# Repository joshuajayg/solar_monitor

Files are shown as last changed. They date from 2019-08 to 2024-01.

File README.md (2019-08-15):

# Solar Monitor

This is a solar power production and use monitoring system based on the LTC4151 IC by Analog.  Data is read by an ESP8266, sent over wifi using MQTT to a Raspberry Pi, stored in a database, then uploaded to a hosted webserver for display.  It is a work in progress but I plan to share all my scripts, web pages, and hardware designs here to help me solve problems and guide people in the right direction who want to setup a similar system.

You can see the system in work at http://yeolecabin.com/solar_complete.php



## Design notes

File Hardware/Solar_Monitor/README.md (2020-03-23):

The board uses six LTC4151-2 ICs, an ESP8266 running NODEMCU and one DROK buck converter.

The wires run from the board to the current shunts needs to be twisted pair wires.  This cuts down on EMI by common mode rejection.  For short runs, CAT5 wire works fine.

When adding a external input to D3, there is a voltage divider used to drop the voltage to 3.3V at the MCU.  You need to calculate these values as follows:
Vout = (Vin * R3) / (R4 + R3)

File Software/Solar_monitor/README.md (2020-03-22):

#Requirements:

    LTC4151 library from https://github.com/kerrydwong/LTC4151
    ESP8266 board zip

Arduino IDE version used: 1.8.5

ESP8266 board version: 2.4.2

Remember to update the "ssid", "password", "mqtt_server", "batteryCapacity", and "batteryEfficiency" to match your setup.

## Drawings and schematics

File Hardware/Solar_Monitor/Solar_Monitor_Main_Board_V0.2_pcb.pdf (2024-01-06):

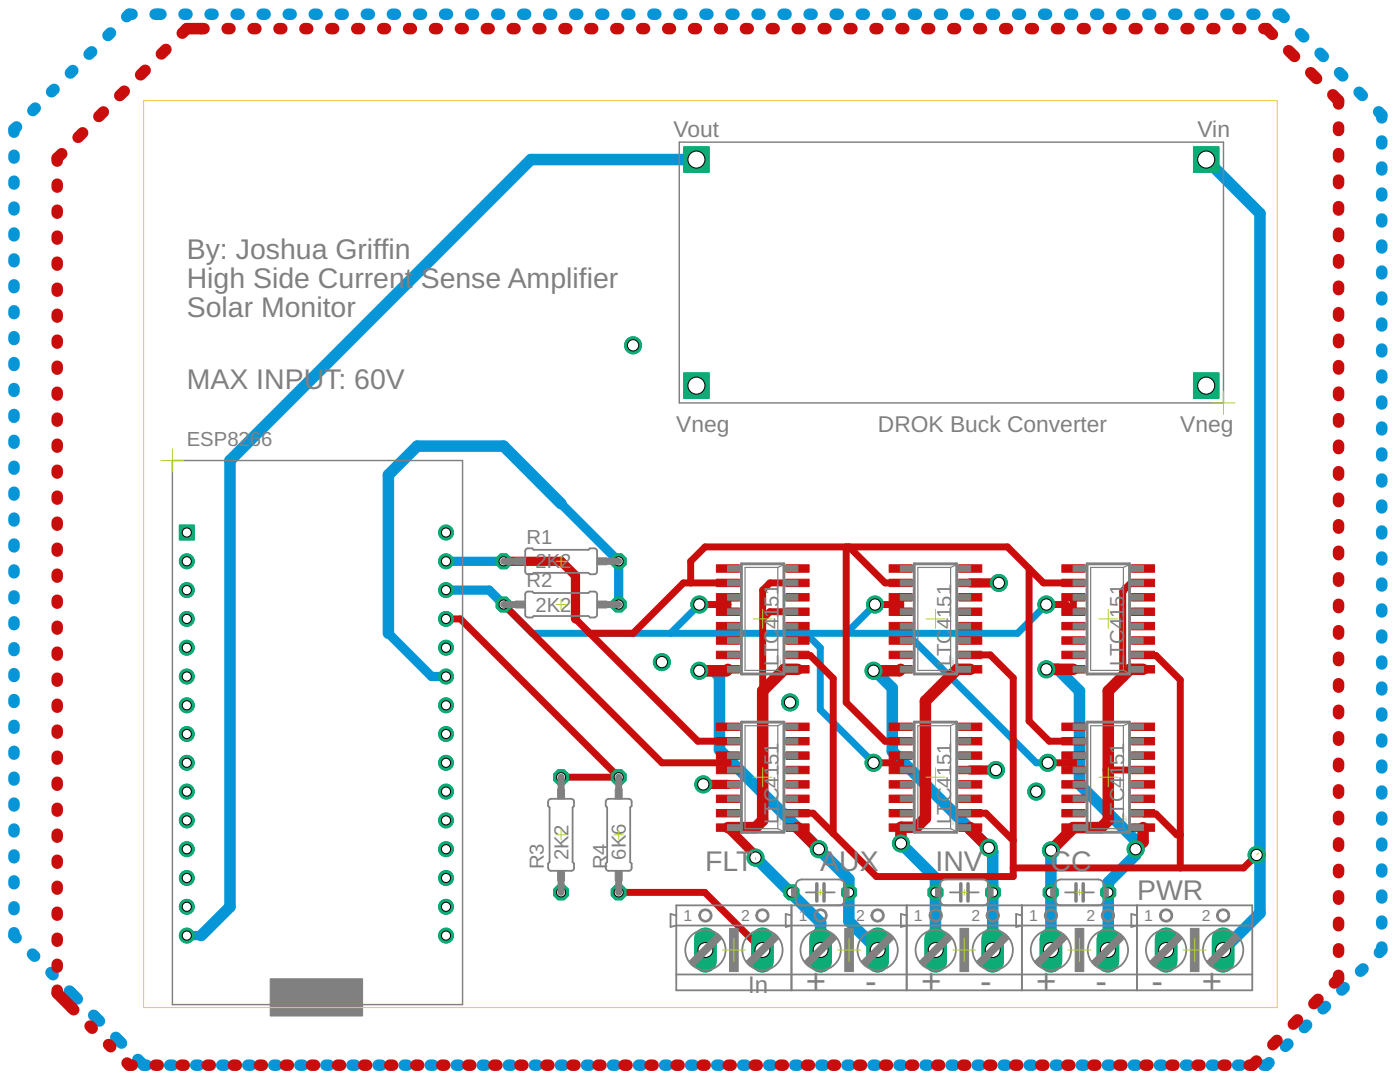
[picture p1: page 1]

By: Joshua Griffin
High Side Current Sense Amplifier
Solar Monitor

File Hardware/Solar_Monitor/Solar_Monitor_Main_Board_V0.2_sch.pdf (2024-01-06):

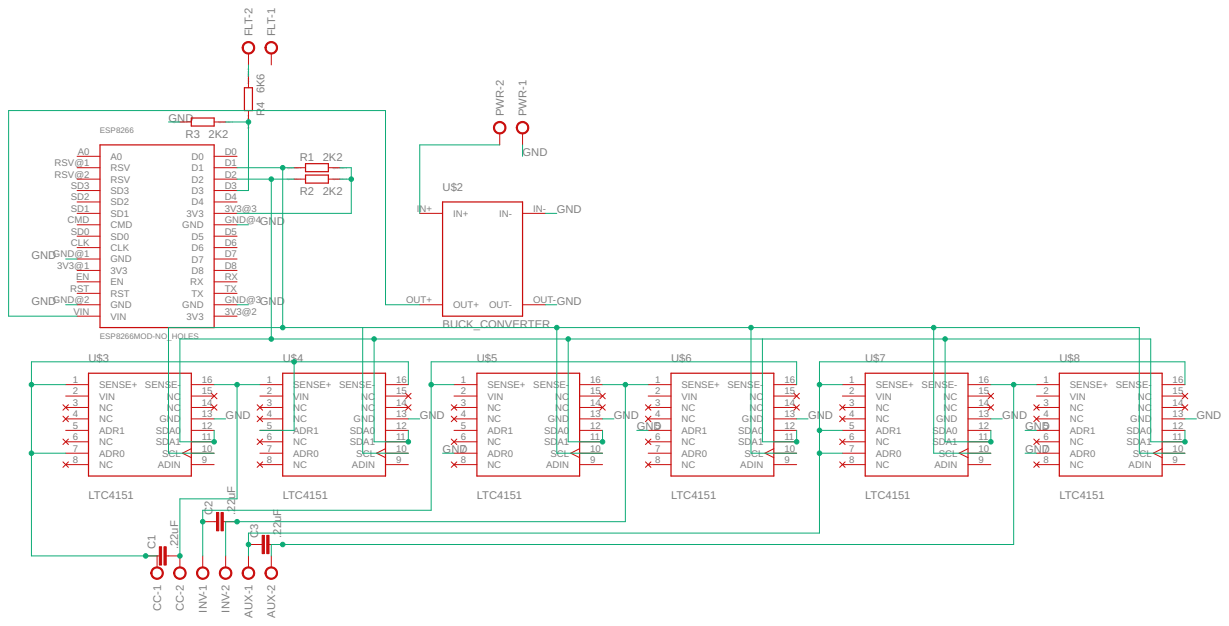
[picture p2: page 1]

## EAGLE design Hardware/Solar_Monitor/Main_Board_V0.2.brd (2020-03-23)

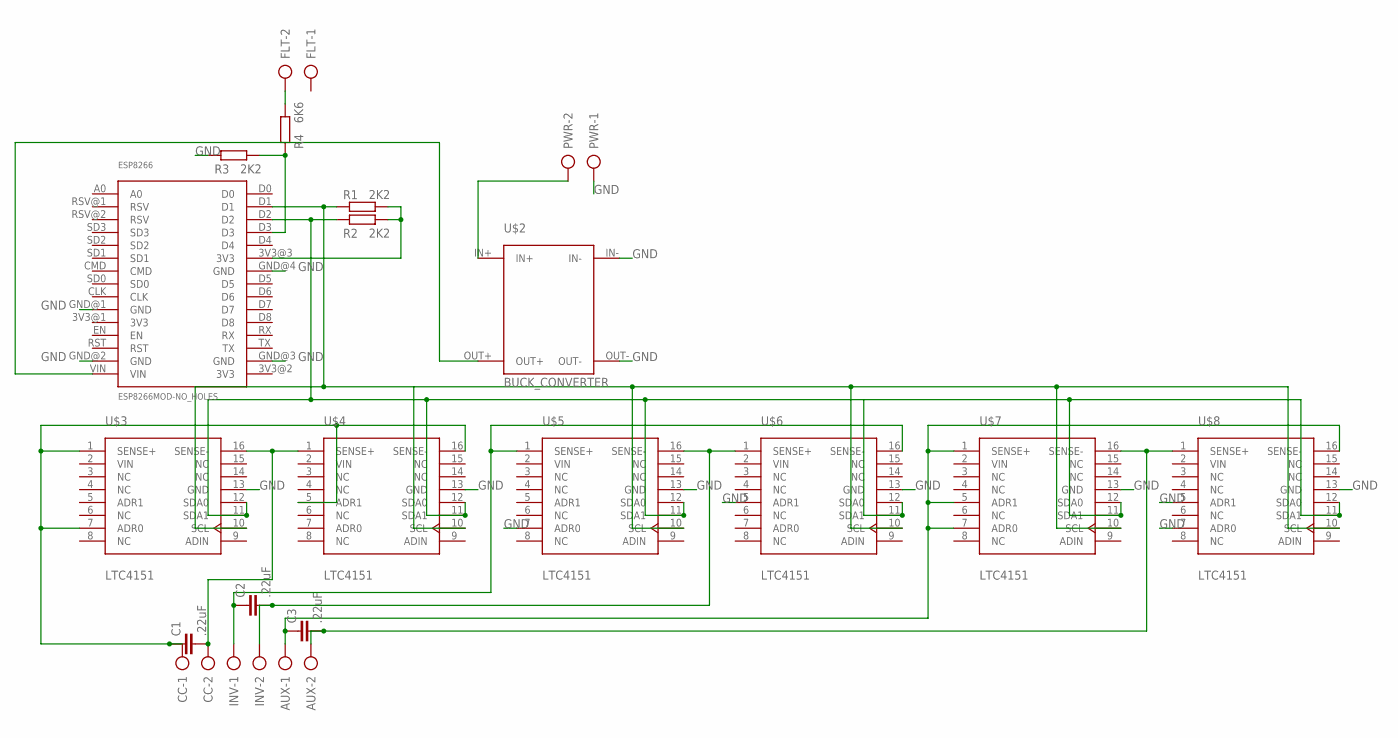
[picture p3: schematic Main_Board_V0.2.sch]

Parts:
AUX: AK500/2
C1, C2, C3: .22uF; C050-024X044
CC: AK500/2
ESP8266: ESP8266MOD-NO_HOLES
FLT: AK500/2
INV: AK500/2
PWR: AK500/2
R1, R2, R3: 2K2; 0207/10
R4: 6K6; 0207/10
U$2: BUCK_CONVERTER
U$3, U$4, U$5, U$6, U$7, U$8: LTC4151; SO16

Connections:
GND: ESP8266.GND@1 (GND), ESP8266.GND@2 (GND), ESP8266.GND@3 (GND), ESP8266.GND@4 (GND), PWR.1, R3.1, U$2.IN-, U$2.OUT-, U$3.13 (GND), U$4.13 (GND), U$5.7 (ADR0), U$5.13 (GND), U$6.5 (ADR1), U$6.13 (GND), U$7.13 (GND), U$8.5 (ADR1), U$8.7 (ADR0), U$8.13 (GND)
unnamed: FLT.2, R4.2
unnamed: ESP8266.D3, R3.2, R4.1
unnamed: ESP8266.VIN, U$2.OUT+
unnamed: C1.1, CC.1, U$3.1 (SENSE+), U$3.7 (ADR0), U$4.5 (ADR1), U$4.16 (SENSE-)
unnamed: C1.2, CC.2, U$3.16 (SENSE-), U$4.1 (SENSE+)
unnamed: C2.1, INV.1, U$5.1 (SENSE+), U$6.16 (SENSE-)
unnamed: C2.2, INV.2, U$5.16 (SENSE-), U$6.1 (SENSE+)
unnamed: AUX.1, C3.1, U$7.1 (SENSE+), U$7.5 (ADR1), U$7.7 (ADR0), U$8.16 (SENSE-)
unnamed: AUX.2, C3.2, U$7.16 (SENSE-), U$8.1 (SENSE+)
unnamed: ESP8266.D2, R2.1, U$3.11 (SDA1), U$3.12 (SDA0), U$4.11 (SDA1), U$4.12 (SDA0), U$5.11 (SDA1), U$5.12 (SDA0), U$6.11 (SDA1), U$6.12 (SDA0), U$7.11 (SDA1), U$7.12 (SDA0), U$8.11 (SDA1), U$8.12 (SDA0)
unnamed: ESP8266.3V3@3 (3V3), R1.2, R2.2
unnamed: ESP8266.D1, R1.1, U$3.10 (SCL), U$4.10 (SCL), U$5.10 (SCL), U$6.10 (SCL), U$7.10 (SCL), U$8.10 (SCL)
VIN: PWR.2, U$2.IN+, U$3.2 (VIN), U$4.2 (VIN), U$5.2 (VIN), U$6.2 (VIN), U$7.2 (VIN), U$8.2 (VIN)

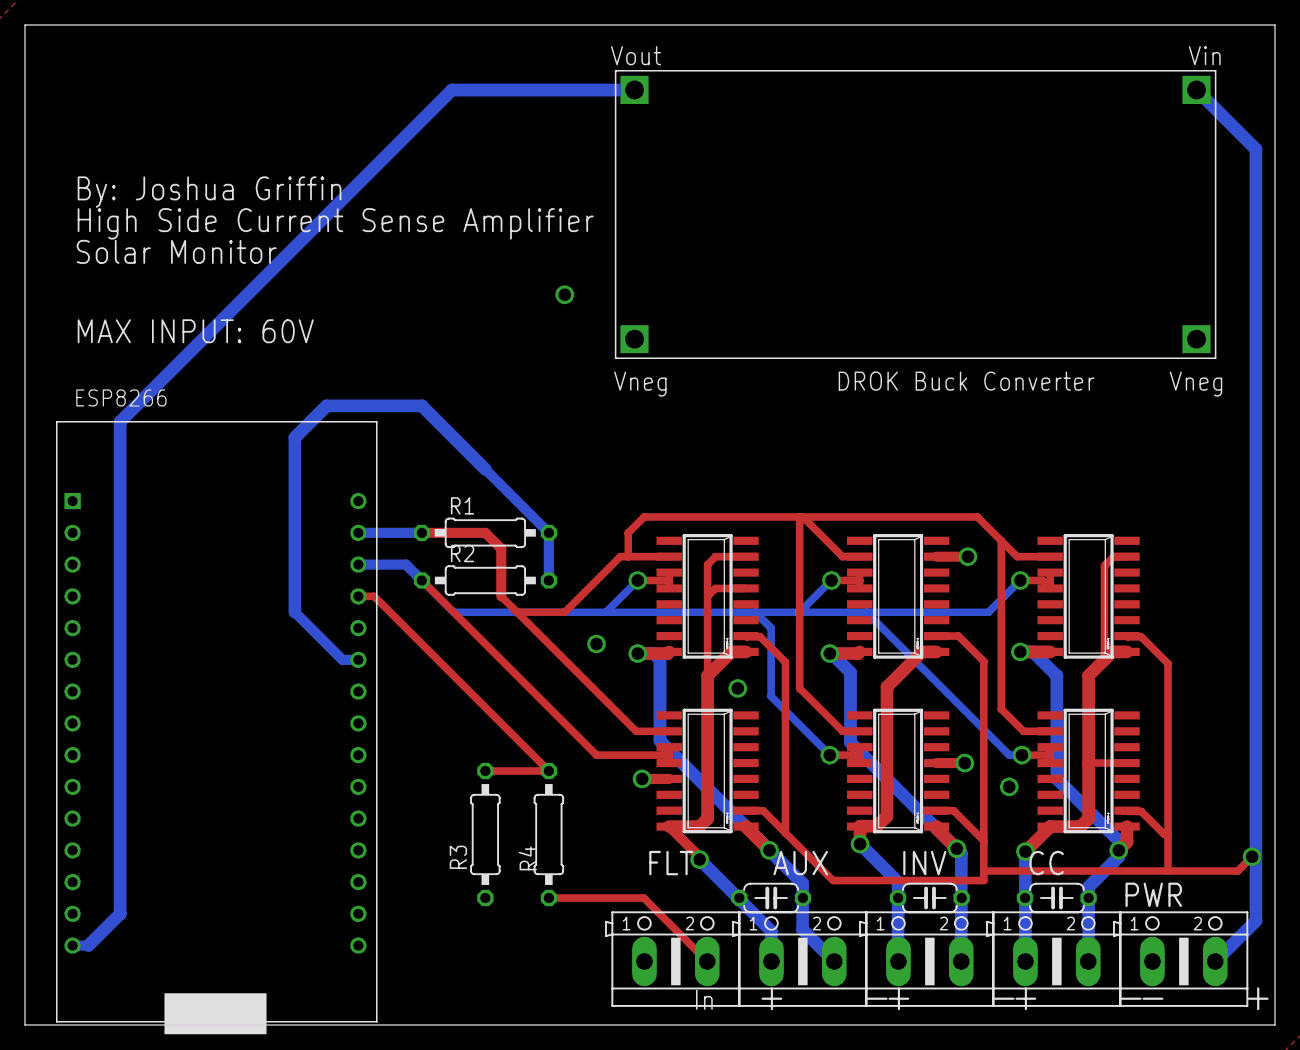
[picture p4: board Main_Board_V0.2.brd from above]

Board: 2 copper layers, 100.0 x 80.0 mm, 20 parts (0 on the bottom side), 14 nets.

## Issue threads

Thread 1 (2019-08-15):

Load on inverter causes false indications on auxiliary

joshuajayg, 2019-08-15:
When the auxiliary bus has no load and the inverter is loaded (which it always it), the auxiliary sensors indicate a positive amperage.  This issue is significant in that it causes bad state of charge calculations over the course of several hours.  If the inverter idles at -3.5A all night and the auxiliary bus is indicating 1.2A, the SOC will be miscalculated by 30% over that time.

I know very little about PCB layout so would appreciate help.
Any ideas @csatt @mohitbhoite ?

The noise on the Auxiliary graph is visible when comparing amp readings across the different sensors at the same time.
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

joshuajayg, 2019-08-24:
Looks like I'm picking up a lot of noise on the sense lines.  Possibly the inverter carrier frequency used to create the sine wave.  Higher frequency is close to 10khz.  I'll change to shielded wires and I'll move the board further away from the inverter and see how that works.  The 60hz dip makes sense.  Every time the inverter produces a sine wave, there is a pulse of power input specifically at 90 degrees.  Also, the carrier frequency increases amplitude when the 60hz voltage dips which would coincide with increased load.  It's the high voltage carrier frequency that bothers me.
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

joshuajayg, 2019-09-07:
I have replaced the cables with twisted pair and the error is greatly improved.  I have also redesigned the PCB to account for an an imbalance in loading the sense wires.  Both ICs on one channel were designed to pull their Vin current from one sense line.  This would cause a small (170uV) drop in voltage across the sense wire if it's 3 feet long and 24awg (typical for CAT5).  Now the IC Vin lines are tied to the same input as the buck converter input.  I will be milling a new PCB soon to test this.

joshuajayg, 2020-03-22:
I have redesigned the board to allow a separate power supply line to feed all the current sense amplifier ICs.  This has fixed all but the smallest about of ripple in the "auxiliary" readings.  The past couple months of testing have shown a negligible amount of error in the auxiliary and therefore calculated battery readings.

Closed 2020-03-22.

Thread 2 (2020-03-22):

Request for input from charge controller aux output

joshuajayg, 2020-03-22:
The Outback MX charge controller series allows the user to setup and output based upon current charge points.  It would be handy to have a circuit designed to take this output from the charge controller and send its status through MQTT to the server.

joshuajayg, 2020-03-23:
Added a voltage divider, input terminal, and routing to D3 for external measurement.  Also added ability to read this value in the sketch though it has not been tested.  Resistor value must be chosen to not allow more than 3.3V to the MCU.

Closed 2020-03-23.

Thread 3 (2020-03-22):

Incorrect label for max voltage

joshuajayg, 2020-03-22:
The max voltage label on the PCB is 90V.  This is based on the current sense amplifier datasheet.  However, the DROK buck converter has a lower max voltage of 60V.

joshuajayg, 2020-03-23:
V0.2 of the board now says max input is 60V to match the buck converter limit.

Closed 2020-03-23.

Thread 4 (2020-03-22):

adin pin not used but measurement called in sketch

joshuajayg, 2020-03-22:
The LTC4151 has a pin available to measure an external voltage (different than battery voltage) but the pin is not broken out on the board.  Calling a reading on this pin is a waste of memory.

joshuajayg, 2020-03-23:
Removed all calls to measure ADIN from sketch.

Closed 2020-03-23.

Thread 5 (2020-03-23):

It would be nice to be able to set the initial values for several reported values

joshuajayg, 2020-03-23:
Things like state of charge, amphours, and watthours get reset when you remove and add power or re-upload the sketch.  It would be handy to be able to set these initial values when uploading the sketch.

joshuajayg, 2020-03-23:
Added initial values in the sketch and a check up setup() to set these initial values in the global variables.

Closed 2020-03-23.

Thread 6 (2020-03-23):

Request for SPIFFS storage of last values

joshuajayg, 2020-03-23:
When the board looses power, the "initial values" are re-read and applied to the current global variables.  A better solution would be to periodically store globals in SPIFFS so that a power cycle of the board, the latest values get re-saved as the initial global variables.

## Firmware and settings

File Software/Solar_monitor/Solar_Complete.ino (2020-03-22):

#include <Wire.h>
#include <LTC4151.h>
#include <ESP8266WiFi.h>
#include <ESP8266mDNS.h>
#include <WiFiUdp.h>
#include <ArduinoOTA.h>
#include <PubSubClient.h>

const char* ssid = "Your_Access_Point";
const char* password = "Your_Password";
const char* mqtt_server = "Server_IP";

const float batteryEfficiency = .97;  // How much of the charge the batteries absorb
const float batteryCapacity = 450;  // Amp Hours

float initialBatteryAmpHours = 450;
float initialInverterWattHours = -2265;
float initialInverterAmpHours = -88.15;
float initialChargeControllerAmpHours = 163.54;
float initialChargeControllerWattHours = 4666;

// Input pins
//#define floatPin D3
  
// Tracking time
unsigned long lastTime1;
unsigned long lastTime2;
unsigned long lastTime3;
unsigned long lastTime4;
unsigned long length1;
unsigned long length2;
unsigned long length3;
unsigned long length4;

// MQTT setup
WiFiClient espClient;
PubSubClient client(espClient);
unsigned long lastMsg = 0;
char msg1[8];
char msg2[8];
char msg3[8];
char msg4[8];
char msg5[8];
char msg6[8];
char msg7[8];
char msg8[8];
char msg9[8];
char msg10[8];
char msg11[8];
char msg12[8];
char msg13[8];
char msg14[8];
char msg15[8];
char msg16[8];
char msg17[8];
char msg18[6];

// Define sensors
LTC4151 sensor1;
LTC4151 sensor2;
LTC4151 sensor3;
LTC4151 sensor4;
LTC4151 sensor5;
LTC4151 sensor6;

//Array setup
const int numReadings1 = 20;
float readings1[numReadings1];
int readIndex1 = 0;
float total1 = 0;
float amp1 = 0;

const int numReadings2 = 20;
float readings2[numReadings2];
int readIndex2 = 0;
float total2 = 0;
float amp2 = 0;

const int numReadings3 = 20;
float readings3[numReadings3];
int readIndex3 = 0;
float total3 = 0;
float amp3 = 0;

const int numReadings4 = 20;
float readings4[numReadings4];
int readIndex4 = 0;
float total4 = 0;
float amp4 = 0;

const int numReadings5 = 20;
float readings5[numReadings5];
int readIndex5 = 0;
float total5 = 0;
float amp5 = 0;

const int numReadings6 = 20;
float readings6[numReadings6];
int readIndex6 = 0;
float total6 = 0;
float amp6 = 0;

// Values
float inverterAmps;
float inverterVolts;
float inverterWatts;
float inverterWattHours;
float inverterAmpHours;
float chargeControllerAmps;
float chargeControllerVolts;
float chargeControllerWatts;
float chargeControllerWattHours;
float chargeControllerAmpHours;
float auxiliaryAmps;
float auxiliaryVolts;
float auxiliaryWatts;
float auxiliaryWattHours;
float auxiliaryAmpHours;
float batteryAmps;
float batteryWatts;
float batteryAmpHours;
float batteryWattHours;

void setup_wifi() {

  delay(10);
  // We start by connecting to a WiFi network
  Serial.println();
  Serial.print("Connecting to ");
  Serial.println(ssid);

  WiFi.mode(WIFI_STA);
  WiFi.begin(ssid, password);

  while (WiFi.status() != WL_CONNECTED) {
    delay(500);
    Serial.print(".");
  }

  randomSeed(micros());

  Serial.println("");
  Serial.println("WiFi connected");
  Serial.println("IP address: ");
  Serial.println(WiFi.localIP());
}

void reconnect() {
  // Loop until we're reconnected
  while (!client.connected()) {
    Serial.print("Attempting MQTT connection...");
    // Create a random client ID
    String clientId = "ESP8266Client-";
    clientId += String(random(0xffff), HEX);
    // Attempt to connect
    if (client.connect(clientId.c_str())) {
      Serial.println("connected");
      // Subscribe
      client.subscribe("midnight");
    } else {
      Serial.print("failed, rc=");
      Serial.print(client.state());
      Serial.println(" try again in 5 seconds");
      // Wait 5 seconds before retrying
      delay(5000);
    }
  }
}

void OTASetup()
{
    // Port defaults to 8266
    // ArduinoOTA.setPort(8266);

    // Hostname defaults to esp8266-[ChipID]
    ArduinoOTA.setHostname("Solar");

    // No authentication by default
    // ArduinoOTA.setPassword("admin");

    // Password can be set with it's md5 value as well
    // MD5(admin) = 21232f297a57a5a743894a0e4a801fc3
    // ArduinoOTA.setPasswordHash("21232f297a57a5a743894a0e4a801fc3");

    ArduinoOTA.onStart([]() {
      String type;
      if (ArduinoOTA.getCommand() == U_FLASH)
        type = "sketch";
      else // U_SPIFFS
        type = "filesystem";

      // NOTE: if updating SPIFFS this would be the place to unmount SPIFFS using SPIFFS.end()
      Serial.println("Start updating " + type);
    });
    ArduinoOTA.onEnd([]() {
      Serial.println("\nEnd");
    });
    ArduinoOTA.onProgress([](unsigned int progress, unsigned int total) {
      Serial.printf("Progress: %u%%\r", (progress / (total / 100)));
    });
    ArduinoOTA.onError([](ota_error_t error) {
      Serial.printf("Error[%u]: ", error);
      if (error == OTA_AUTH_ERROR) Serial.println("Auth Failed");
      else if (error == OTA_BEGIN_ERROR) Serial.println("Begin Failed");
      else if (error == OTA_CONNECT_ERROR) Serial.println("Connect Failed");
      else if (error == OTA_RECEIVE_ERROR) Serial.println("Receive Failed");
      else if (error == OTA_END_ERROR) Serial.println("End Failed");
    });
    ArduinoOTA.begin();
    Serial.println("Ready");
    Serial.print("IP address: ");
    Serial.println(WiFi.localIP());
}

void setInitialValues() {
  
    // Set initial values
    batteryAmpHours = initialBatteryAmpHours;
    inverterWattHours = initialInverterWattHours;
    inverterAmpHours = initialInverterAmpHours;
    chargeControllerAmpHours = initialChargeControllerAmpHours;
    chargeControllerWattHours = initialChargeControllerWattHours;
}

/*
void checkForFloat() {
  bool floatState = digitalRead(floatPin);
  if(floatState){
    batteryAmpHours = batteryCapacity;
  }
}
*/

void getReadings()
{
  unsigned long now = millis();

//array for amp smoothing
  total1 = total1 - readings1[readIndex1];
  readings1[readIndex1] = (sensor1.getLoadCurrent(0.000375));
  total1 = total1 + readings1[readIndex1];
  readIndex1 = readIndex1 + 1;

  if (readIndex1 >= numReadings1) {
    readIndex1 = 0;
  }
  amp1 = total1 / numReadings1;

  //Max input voltage is 102.4V full scale and 25mV resolution.
  float volt1 = sensor1.getInputVoltage();
  //Calculated watts from amp and volt.
  float watt1 = amp1*volt1;

  total2 = total2 - readings2[readIndex2];
  readings2[readIndex2] = (sensor2.getLoadCurrent(0.000375));
  total2 = total2 + readings2[readIndex2];
  readIndex2 = readIndex2 + 1;

  if (readIndex2 >= numReadings2) {
    readIndex2 = 0;
  }
  amp2 = total2 / numReadings2;

  float volt2 = sensor2.getInputVoltage();
  float watt2 = amp2*volt2;

  total3 = total3 - readings3[readIndex3];
  readings3[readIndex3] = (sensor3.getLoadCurrent(0.000375));
  total3 = total3 + readings3[readIndex3];
  readIndex3 = readIndex3 + 1;

  if (readIndex3 >= numReadings3) {
    readIndex3 = 0;
  }
  amp3 = total3 / numReadings3;

  float volt3 = sensor3.getInputVoltage();
  float watt3 = amp3*volt3;

  total4 = total4 - readings4[readIndex4];
  readings4[readIndex4] = (sensor4.getLoadCurrent(0.000375));
  total4 = total4 + readings4[readIndex4];
  readIndex4 = readIndex4 + 1;

  if (readIndex4 >= numReadings4) {
    readIndex4 = 0;
  }
  amp4 = total4 / numReadings4;

  float volt4 = sensor4.getInputVoltage();
  float watt4 = amp4*volt4;

  total5 = total5 - readings5[readIndex5];
  readings5[readIndex5] = (sensor5.getLoadCurrent(0.000375));
  total5 = total5 + readings5[readIndex5];
  readIndex5 = readIndex5 + 1;

  if (readIndex5 >= numReadings5) {
    readIndex5 = 0;
  }
  amp5 = total5 / numReadings5;
  
  float volt5 = sensor5.getInputVoltage();
  float watt5 = amp5*volt5;

  total6 = total6 - readings6[readIndex6];
  readings6[readIndex6] = (sensor6.getLoadCurrent(0.000375));
  total6 = total6 + readings6[readIndex6];
  readIndex6 = readIndex6 + 1;

  if (readIndex6 >= numReadings6) {
    readIndex6 = 0;
  }
  amp6 = total6 / numReadings6;

  float volt6 = sensor6.getInputVoltage();
  float watt6 = amp6*volt6;

  // Choose the greater of the two readings and set them as positive or negative
  if (amp1 > amp2) {
    chargeControllerAmps = -amp1;
    chargeControllerWatts = -watt1;
  } else {
    chargeControllerAmps = amp2;
    chargeControllerWatts = watt2;
  }

  // Calculate WH and AH
  length1 = (now-lastTime1);
  lastTime1 = now;
  float chargeControllerWattHoursNow = (chargeControllerWatts*length1/3600000);
  chargeControllerWattHours = (chargeControllerWattHoursNow + chargeControllerWattHours);
  float chargeControllerAmpHoursNow = (chargeControllerAmps*length1/3600000);
  chargeControllerAmpHours = (chargeControllerAmpHoursNow + chargeControllerAmpHours);

  if (volt1 > volt2) {
    chargeControllerVolts = volt1;
  } else{
    chargeControllerVolts = volt2;
  }

  if (amp3 > amp4) {
    inverterAmps = -amp3;
    inverterWatts = -watt3;
  } else {
    inverterAmps = amp4;
    inverterWatts = watt4;
  }

  length2 = (now-lastTime2);
  lastTime2 = now;
  float inverterWattHoursNow = (inverterWatts*length2/3600000);
  inverterWattHours = (inverterWattHoursNow + inverterWattHours);
  float inverterAmpHoursNow = (inverterAmps*length2/3600000);
  inverterAmpHours = (inverterAmpHoursNow + inverterAmpHours);
  
  if (volt3 > volt4) {
    inverterVolts = volt3;
  } else{
    inverterVolts = volt4;
  }

  if (amp5 > amp6) {
    auxiliaryAmps = -amp5;
    auxiliaryWatts = -watt5;
  } else {
    auxiliaryAmps = amp6;
    auxiliaryWatts = watt6;
  }

  length3 = (now-lastTime3);
  lastTime3 = now;
  float auxiliaryWattHoursNow = (auxiliaryWatts*length3/3600000);
  auxiliaryWattHours = (auxiliaryWattHoursNow + auxiliaryWattHours);
  float auxiliaryAmpHoursNow = (auxiliaryAmps*length3/3600000);
  auxiliaryAmpHours = (auxiliaryAmpHoursNow + auxiliaryAmpHours);
  
  if (volt5 > volt6) {
    auxiliaryVolts = volt5;
  } else{
    auxiliaryVolts = volt6;
  }

  batteryWatts = (chargeControllerWatts + inverterWatts + auxiliaryWatts);
  batteryAmps = (chargeControllerAmps + inverterAmps + auxiliaryAmps);
  
  length4 = (now-lastTime4);
  lastTime4 = now;
  float batteryWattHoursNow = (batteryWatts*length4/3600000);
  batteryWattHours = (batteryWattHoursNow + batteryWattHours);
  float batteryAmpHoursNow = (batteryAmps*length4/3600000);

  // Correct battery charge for battery inefficiency
  if (batteryAmpHoursNow > 0) {
    batteryAmpHours = (batteryAmpHoursNow*batteryEfficiency + batteryAmpHours);
  }
  else {
    batteryAmpHours = (batteryAmpHoursNow + batteryAmpHours);
  }
  
}

void printSerial()
{
  Serial.print(chargeControllerAmps);
  Serial.print("  ");
  Serial.print(chargeControllerWatts);
  Serial.print("  ");
  Serial.print(inverterAmps);
  Serial.print("  ");
  Serial.println(inverterWatts);
  
}

void sendMQTT()
{
  if (!client.connected()) {
    reconnect();
  }
  client.loop();
  unsigned long now = millis();
  float(heap) = ESP.getFreeHeap();
  if (now - lastMsg > 5000) {  // send MQTT every 5000 ms
    lastMsg = now;
    snprintf (msg1, 7, "%3.2f", chargeControllerAmps);
    snprintf (msg2, 7, "%3.2f", chargeControllerVolts);
    snprintf (msg3, 8, "%4.2f", chargeControllerWatts);
    snprintf (msg4, 7, "%3.2f", inverterAmps);
    snprintf (msg5, 7, "%3.2f", inverterVolts);
    snprintf (msg6, 8, "%4.2f", inverterWatts);
    snprintf (msg7, 7, "%3.2f", auxiliaryAmps);
    snprintf (msg8, 7, "%3.2f", auxiliaryVolts);
    snprintf (msg9, 8, "%4.2f", auxiliaryWatts);
    snprintf (msg10, 7, "%5.0f", chargeControllerWattHours);
    snprintf (msg11, 8, "%4.2f", chargeControllerAmpHours);
    snprintf (msg12, 7, "%5.0f", inverterWattHours);
    snprintf (msg13, 8, "%4.2f", inverterAmpHours);
    snprintf (msg14, 7, "%3.2f", batteryAmps);
    snprintf (msg15, 8, "%4.2f", batteryAmpHours);
    snprintf (msg16, 7, "%5.0f", auxiliaryWattHours);
    snprintf (msg17, 8, "%4.2f", auxiliaryAmpHours);
    snprintf (msg18, 6, "%6.0f", heap); 
    
    client.publish("solar/CC/amps", msg1);
    client.publish("solar/CC/volts", msg2);
    client.publish("solar/CC/watts", msg3);
    client.publish("solar/inverter/amps", msg4);
    client.publish("solar/inverter/volts", msg5);
    client.publish("solar/inverter/watts", msg6);
    client.publish("solar/auxiliary/amps", msg7);
    client.publish("solar/auxiliary/volts", msg8);
    client.publish("solar/auxiliary/watts", msg9);
    client.publish("solar/CC/watthours", msg10);
    client.publish("solar/CC/amphours", msg11);
    client.publish("solar/inverter/watthours", msg12);
    client.publish("solar/inverter/amphours", msg13);
    client.publish("solar/battery/amps", msg14);
    client.publish("solar/battery/amphours", msg15);
    client.publish("solar/auxiliary/watthours", msg16);
    client.publish("solar/auxiliary/amphours", msg17);
    client.publish("solar/memory", msg18);
  }
}

void chargeState() {
  if (batteryAmpHours > batteryCapacity) {
    batteryAmpHours = batteryCapacity;
  }
  
}
void callback(char* topic, byte* payload, unsigned int length) {
  Serial.print("Message arrived [");
  Serial.print(topic);
  Serial.print("] ");
  for (int i=0;i<length;i++) {
    Serial.print((char)payload[i]);
  }
  Serial.println();

  if ((char)payload[0] == '1') {
    chargeControllerAmpHours = 0;
    chargeControllerWattHours = 0;
    inverterAmpHours = 0;
    inverterWattHours = 0;
    auxiliaryAmpHours = 0;
    auxiliaryWattHours = 0;
  }
}

void setup()
{   
    // Start serial connection
    Serial.begin(9600);
    while (!Serial);

//    pinMode(floatPin, INPUT);

    // Connect to WiFi
    setup_wifi();

    // Setup MQTT server
    client.setServer(mqtt_server, 1883);
    client.setCallback(callback);

    // OTA setup
    OTASetup();
    
    Wire.begin();

    // Initiate sensors (Address pins: L=Low, H=High, F=Float)
    sensor1.init(LTC4151::H, LTC4151::F);
    sensor2.init(LTC4151::F, LTC4151::H);
    sensor3.init(LTC4151::L, LTC4151::F);
    sensor4.init(LTC4151::F, LTC4151::L);
    sensor5.init(LTC4151::H, LTC4151::H);
    sensor6.init(LTC4151::L, LTC4151::L);

    //Arrays
    for (int thisReading1 = 0; thisReading1 < numReadings1; thisReading1++) {
      readings1[thisReading1] = 0;
    }
    for (int thisReading2 = 0; thisReading2 < numReadings2; thisReading2++) {
      readings2[thisReading2] = 0;
    }
    for (int thisReading3 = 0; thisReading3 < numReadings3; thisReading3++) {
      readings3[thisReading3] = 0;
    }
    for (int thisReading4 = 0; thisReading4 < numReadings4; thisReading4++) {
      readings4[thisReading4] = 0;
    }
    for (int thisReading5 = 0; thisReading5 < numReadings5; thisReading5++) {
      readings5[thisReading5] = 0;
    }
    for (int thisReading6 = 0; thisReading6 < numReadings6; thisReading6++) {
      readings6[thisReading6] = 0; 
    }               

    // Setup time
    lastTime1 = 0;
    lastTime2 = 0;
    lastTime3 = 0;

    setInitialValues();  //disable this if you want to start at zero
}

void loop()
{
//  checkForFloat();
  getReadings();
  chargeState();
  printSerial();
  sendMQTT();
  
  ArduinoOTA.handle();
  delay(250);
}

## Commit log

2019-08-15 Added Solar_Monitor board
    Added the first rendition of the solar monitor board schematic and PCB layout. Files are create in EAGLE.
    [Main_Board.brd, Main_Board.sch]
2020-03-22 Added V0.2 of board
    -Fixed IC power one problem
    -Fixed mislabel of max voltage
    -Added aux input option
    [Main_Board_V0.2.brd, Main_Board_V0.2.sch]
2020-03-22 Update Solar_Complete.ino
    -Removed ADIN readings
    -Added ability to read auxiliary input on pin D3
    -Added ability to set initial values of several parameters so it reads correctly on startup
    [Solar_Complete.ino]
2020-03-23 Update README.md
    Added voltage divider equation
2021-08-22 Adding PDF versions of the schematic and pcb
    For easier viewing for those without Eagle already installed
